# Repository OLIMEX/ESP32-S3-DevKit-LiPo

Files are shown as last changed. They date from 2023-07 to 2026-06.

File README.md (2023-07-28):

# ESP32-S3-DevKit-LiPo
ESP32-S3 development board with JTAG/USB-OTG and LiPo charger

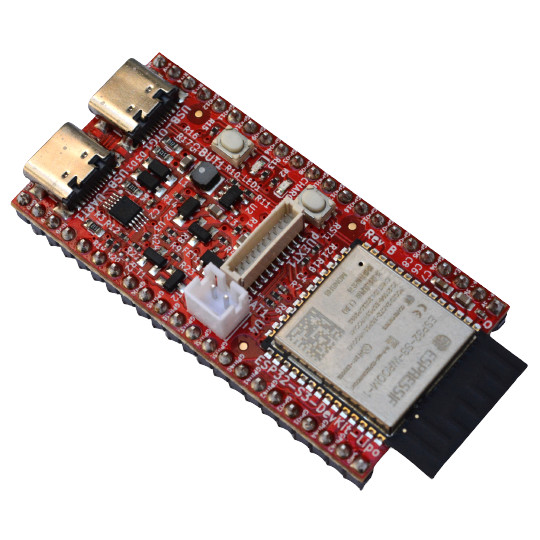
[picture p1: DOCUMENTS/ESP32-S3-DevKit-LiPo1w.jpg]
ESP32-S3-DevKit-LiPo1w


ESP32-S3-DevKit-LiPo is small board capable to run Linux kernel 6.3

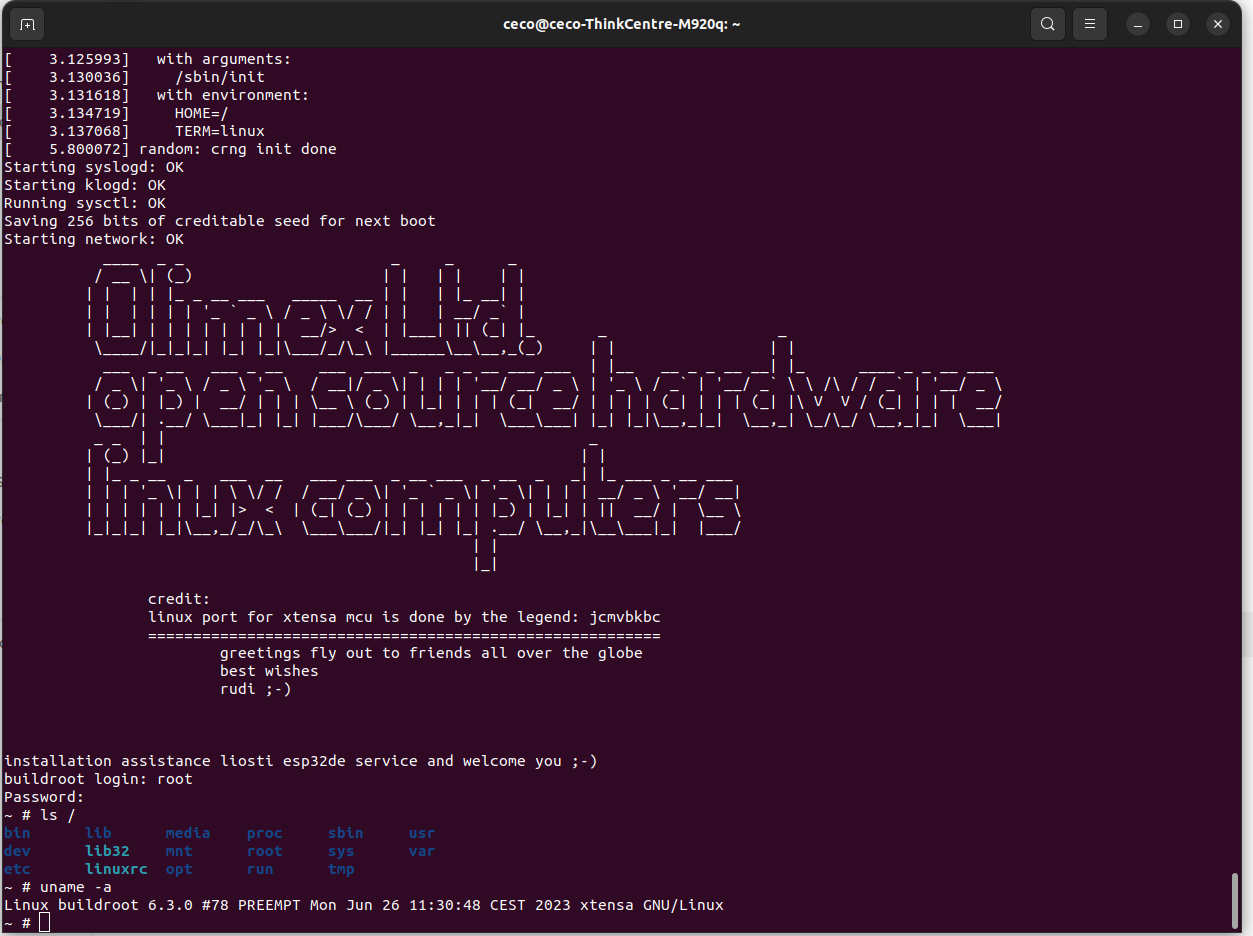
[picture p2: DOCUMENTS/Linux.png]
Linux


## Features

* ESP32-S3-WROOM-1-N8R8 8MB RAM 8 MB Flash
* Green Status LED
* Yellow Charge LED
* pUEXT connector
* USB-C power supply and USB-Serial programmer
* USB-C OTG JTAG/Serial connector
* LiPo charger
* LiPo battery connector
* External power sense
* Battery measurement
* Automatic power supply switch between USB and LiPo
* RESET button
* USER button

## Licenses

* Hardware is released under CERN Open Hardware Licence Version 2 - Strongly Reciprocal, all silkscreen credits to Olimex should remain;
* Software is released under GPL3 Licensee
* Documentation is released under CC BY-SA 3.0

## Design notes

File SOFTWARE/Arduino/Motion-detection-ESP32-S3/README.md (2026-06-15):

# CSI Motion and Position Demo

Arduino Wi-Fi CSI motion and room-zone sensing demo for the Olimex ESP32-S3-DevKit-LiPo and other ESP32-S3 boards.

This project lets you test two related ideas:

- Motion detection: show when something changes in the radio path.
- Position / room-zone detection: collect labels such as `empty`, `center`, `door`, or `desk`, then show a live browser-side guess.

Start with the one-board example. After that, use the multi-board receiver and transmitter examples for the real experiment.

## What You Need

- Arduino IDE 2.x, or Arduino IDE 1.8.x.
- ESP32 Arduino core installed in Arduino IDE.
- One Olimex ESP32-S3-DevKit-LiPo for the first test.
- For the recommended room test: three boards total.
  - 1 board runs `MultiBoardReceiverNode`.
  - 2 boards run `MultiBoardTransmitterNode`.
- USB cable for programming.
- Optional LiPo batteries for testing transmitters away from the computer.

No extra Arduino libraries are required. The examples use libraries that come with the ESP32 Arduino core: `WiFi`, `WebServer`, `WiFiUdp`, and `Preferences`.

## Install Arduino IDE

1. Download Arduino IDE from:
   - https://www.arduino.cc/en/software
2. Install it.
3. Start Arduino IDE once.

## Install ESP32 Board Support

Arduino IDE does not support ESP32 boards until you install the ESP32 board package.

1. Open Arduino IDE.
2. Go to `File > Preferences`.
3. Find `Additional boards manager URLs`.
4. Add this URL:

```text
https://espressif.github.io/arduino-esp32/package_esp32_index.json
```

5. Press `OK`.
6. Go to `Tools > Board > Boards Manager...`.
7. Search for `esp32`.
8. Install `esp32 by Espressif Systems`.
9. Restart Arduino IDE.

This is the stable ESP32 package URL from Espressif's Arduino-ESP32 install documentation:

- https://docs.espressif.com/projects/arduino-esp32/en/latest/installing.html

## Get This Project

When this project is on GitHub:

1. Open the GitHub repository page.
2. Press `Code`.
3. Press `Download ZIP`.
4. Extract the ZIP somewhere easy to find.

The project folder should contain files like this:

```text
CSI-Motion-and-Position-Demo/
  library.properties
  README.md
  src/
    MotionEsp32S3.h
    MotionEsp32S3.cpp
  examples/
    SingleBoardDashboard/
      SingleBoardDashboard.ino
    MultiBoardReceiverNode/
      MultiBoardReceiverNode.ino
    MultiBoardTransmitterNode/
      MultiBoardTransmitterNode.ino
    LoggerOnly/
      LoggerOnly.ino
```

The exact top folder name can be different. What matters is that `library.properties`, `src`, and `examples` are inside the same project folder.

## Install This Project In Arduino IDE

The easiest method is Arduino's ZIP library installer.

1. Make sure the whole project folder contains `library.properties`, `src`, and `examples`.
2. Zip the whole project folder.
3. In Arduino IDE, go to `Sketch > Include Library > Add .ZIP Library...`.
4. Select the ZIP file.
5. Wait for Arduino IDE to import it.
6. Check `File > Examples > CSI Motion and Position Demo`.

You should see:

- `SingleBoardDashboard`
- `MultiBoardReceiverNode`
- `MultiBoardTransmitterNode`
- `LoggerOnly`

If Arduino says the ZIP is invalid, the ZIP is probably nested incorrectly. Open the ZIP and check that it contains one project folder, and inside that folder are `library.properties`, `src`, and `examples`.

## Manual Install Option

Use this only if the ZIP installer does not work.

1. In Arduino IDE, open `File > Preferences`.
2. Note the `Sketchbook location`.
3. Open that folder in Windows Explorer.
4. Open or create the `libraries` folder.
5. Copy the whole project folder into `libraries`.

On Windows the final layout should look similar to:

```text
C:\Users\YOUR_NAME\Documents\Arduino\libraries\CSI_Motion_and_Position_Demo\
  library.properties
  src\
  examples\
```

Restart Arduino IDE after copying manually.

## Olimex ESP32-S3-DevKit-LiPo Board Settings

Connect the board through the onboard `USB-OTG1` native USB Type-C connector.

In Arduino IDE, select the board:

- `Tools > Board > esp32 > OLIMEX ESP32-S3-DevKit-Lipo`

If that exact board name is not available, update the ESP32 board package first. For quick experiments, a compatible ESP32-S3 board profile can work, but the Olimex profile is recommended for this board.

Settings tested with the USB-OTG1 connector:

| Arduino IDE menu | Value |
| --- | --- |
| Upload Speed | `921600` |
| USB Mode | `Hardware CDC and JTAG` |
| USB CDC On Boot | `Enabled` |
| USB Firmware MSC On Boot | `Disabled` |
| USB DFU On Boot | `Disabled` |
| Upload Mode | `USB-OTG CDC (TinyUSB)` |
| CPU Frequency | `240MHz (WiFi)` |
| Flash Mode | `QIO 80MHz` |
| Flash Size | `8MB (64Mb)` |
| Partition Scheme | `8M with spiffs (3MB APP/1.5MB SPIFFS)` |
| Core Debug Level | `None` |
| PSRAM | `OPI PSRAM` |
| Arduino Runs On | `Core 1` |
| Events Run On | `Core 1` |
| Erase All Flash Before Sketch Upload | `Disabled` |
| JTAG Adapter | `Disabled` |
| Port | the detected `ESP32 Family Device` COM port |

If you use an external USB-UART adapter instead of the native USB connector, the port and upload mode can be different.

## First Test: One Board

Use this first. It proves that the library, board package, upload, serial port, Wi-Fi, and dashboard all work.

1. Open Arduino IDE.
2. Go to `File > Examples > CSI Motion and Position Demo > SingleBoardDashboard`.
3. Edit these lines near the top:

```cpp
const char *WIFI_SSID = "YOUR_WIFI_NAME";
const char *WIFI_PASS = "YOUR_WIFI_PASSWORD";
```

4. Select your board and port in `Tools`.
5. Press `Upload`.
6. Open `Tools > Serial Monitor`.
7. Set baud rate to `115200`.

After Wi-Fi connects, Serial Monitor prints something like:

```text
Dashboard: http://192.168.0.139/
```

Open that address from a phone or computer on the same Wi-Fi network.

This one-board example joins your normal Wi-Fi network. It does not create its own access point.

Expected serial output looks like:

```text
score:0.55 threshold:1.10 motion:0 confidence:50 packets:656 links:1 best:F0:F5:BD:02:28:A0 rssi:-51
```

If you see changing packet counts and a dashboard in the browser, the basic setup works.

## One-Board Placement

For `SingleBoardDashboard`:

- Put the router/AP and the ESP32-S3 on opposite sides of the test area.
- Keep the board and router fixed.
- Keep the room still for the first 8 seconds after boot.
- Walk between the router and the board and watch the score.

This mode is only a quick proof. It depends on router traffic and the local Wi-Fi environment. The multi-board setup is more repeatable.

## Recommended Test: Three Boards

For a practical motion and position test, use three boards:

| Board | Example to flash | Role |
| --- | --- | --- |
| Board 1 | `MultiBoardReceiverNode` | Creates Wi-Fi AP and dashboard |
| Board 2 | `MultiBoardTransmitterNode` | Sends packets to receiver |
| Board 3 | `MultiBoardTransmitterNode` | Sends packets to receiver |

The receiver creates its own Wi-Fi network:

```text
SSID: MOTION-RX
Password: motion1234
Dashboard: http://192.168.4.1
```

Your room router is not needed for the multi-board demo.

## Flash The Receiver

1. Open `File > Examples > CSI Motion and Position Demo > MultiBoardReceiverNode`.
2. Select the Olimex ESP32-S3 board and port.
3. Upload.
4. Open Serial Monitor at `115200`.
5. Confirm it prints:

```text
Receiver access point started.
SSID: MOTION-RX
Password: motion1234
Dashboard: http://192.168.4.1/
```

## Flash The Transmitters

For the first transmitter:

1. Open `File > Examples > CSI Motion and Position Demo > MultiBoardTransmitterNode`.
2. Set:

```cpp
const char *NODE_ID = "node-1";
```

3. Upload to board 2.

For the second transmitter:

1. Keep the same sketch open.
2. Change:

```cpp
const char *NODE_ID = "node-2";
```

3. Upload to board 3.

The transmitters should keep these defaults unless you changed the receiver:

```cpp
const char *RX_SSID = "MOTION-RX";
const char *RX_PASS = "motion1234";
```

Serial Monitor on each transmitter prints its MAC address:

```text
Node MAC: B0:4E:26:6E:B2:73
```

Write down each transmitter MAC if you later want to use a custom allowlist.

## Open The Multi-Board Dashboard

1. Power the receiver.
2. Power the transmitter boards.
3. On your phone or laptop, connect to Wi-Fi network `MOTION-RX`.
4. Use password `motion1234`.
5. Open:

```text
http://192.168.4.1
```

The page title is `CSI Motion and Position Demo`.

The page has two tabs:

- `Motion`: live motion score and calibration.
- `Position`: label collection and live room-zone guess.

## Multi-Board Placement

Start simple:

- Put the receiver near one wall or corner.
- Put transmitter 1 on another side of the room.
- Put transmitter 2 on a different side of the room.
- The three boards should roughly form a triangle around the area.
- Keep antennas vertical.
- Keep all boards fixed during a test.
- Do not let boards swing from USB cables.

A person should cross at least one transmitter-to-receiver radio path when moving through the room.

For bigger rooms, 3 to 5 transmitters can be useful. The receiver tracks up to 8 active links, but the phone/laptop also uses one SoftAP client slot. If the dashboard `Dropped` counter rises quickly, reduce `PACKETS_PER_SECOND` in every transmitter to `25` to `35`.

## Motion Calibration

Use this after placing the receiver and transmitters:

1. Open `http://192.168.4.1`.
2. Go to the `Motion` tab.
3. Wait until active links appear.
4. Press `Reset baseline`.
5. Keep the room still.
6. Press `Learn idle`.
7. Stay still during the 8 second idle sample.
8. Press `Learn motion`.
9. Move through the path you want to detect during the 20 second motion sample.
10. Press `Apply suggested`.
11. Test normal movement and no movement.
12. Press `Save settings` if the threshold works well.

Lower threshold means more sensitive but more false positives. Higher threshold means fewer false positives but it can miss small motion.

## Position / Room-Zone Learning

Position mode is for labels such as:

- `empty`
- `center`
- `door`
- `desk`
- `bed`
- `sofa`

The model runs in the browser. It learns from the labels you collect during the current browser session.

Basic test with `empty` and `center`:

1. Open `http://192.168.4.1`.
2. Go to the `Position` tab.
3. Select label `empty`.
4. Leave the room empty and press `Start 60s`.
5. Wait until recording stops, or press `Stop`.
6. Select label `center`.
7. Stand in the center of the room and press `Start 60s`.
8. Wait until recording stops, or press `Stop`.
9. Watch `Live guess`.
10. Leave the room empty and check that it tends toward `empty`.
11. Stand in the center and check that it tends toward `center`.

The live guess is a simple nearest-centroid classifier. It compares the current CSI rows against the labels stored in the browser. It is meant for quick experiments, not precision indoor positioning.

Important:

- Keep all boards fixed while collecting all labels.
- If you move a board, collect the labels again.
- If you refresh or close the browser tab, the temporary model is lost.
- Press `Download CSV` before leaving the page if you want to keep the dataset.

## LoggerOnly Example

`LoggerOnly` is a smaller receiver sketch for data collection only.

Use it when:

- You want the simplest phone-friendly CSV logger.
- You do not need the full motion dashboard.
- You want optional CSV over USB Serial by setting:

```cpp
#define PRINT_SERIAL_CSV 1
```

For most users, start with `MultiBoardReceiverNode` instead.

## Filtering Links

The dashboard can show several links because it sees CSI from different Wi-Fi transmitters.

For `SingleBoardDashboard`, the default is to filter to the connected router/AP.

For `MultiBoardReceiverNode`, the default is:

```cpp
#define CSI_FILTER_MODE CSI_FILTER_NONE
```

This lets all transmitter nodes appear.

If phones or other clients appear as unwanted links, edit the receiver sketch:

```cpp
#define CSI_FILTER_MODE CSI_FILTER_CUSTOM_LIST
#define CSI_CUSTOM_MAC_COUNT 2
const uint8_t CSI_CUSTOM_MAC_ALLOWLIST[MotionEsp32S3::kMaxLinks][6] = {
  {0xB0, 0x4E, 0x26, 0x6E, 0xB2, 0x73},
  {0xF0, 0xF5, 0xBD, 0x02, 0x28, 0xA0},
};
```

Use the MAC addresses printed by each transmitter as `Node MAC: ...`.

## What The Dashboard Shows

- Motion score
- Motion/calm state
- Threshold
- Confidence
- Best link MAC
- Active links
- Per-link RSSI, score, packets, and state
- Dropped queue count
- Free heap and minimum free heap
- Motion calibration controls
- Position labels and live guess
- CSV download

Hover the mouse over dashboard buttons to see short tooltips.

## Troubleshooting

### The examples do not appear in Arduino IDE

- Restart Arduino IDE.
- Check that the ZIP was imported with `Sketch > Include Library > Add .ZIP Library...`.
- Check that `library.properties`, `src`, and `examples` are inside the installed library folder.

### ESP32 boards do not appear in the Board menu

- Recheck the Boards Manager URL.
- Install `esp32 by Espressif Systems` from Boards Manager.
- Restart Arduino IDE.

### Upload fails

- Check that the correct COM port is selected.
- Check the USB cable supports data, not only charging.
- For the Olimex USB-OTG1 connector, use the settings in this README.
- Try pressing the board reset button and uploading again.

### Serial Monitor shows nothing

- Set baud rate to `115200`.
- Press reset on the board.
- Make sure the sketch actually uploaded to this board.

### Single-board dashboard does not open

- Make sure the board joined your Wi-Fi.
- Your phone/computer must be on the same Wi-Fi network.
- Use the IP printed in Serial Monitor.

### Multi-board dashboard does not open

- Connect your phone/laptop to Wi-Fi `MOTION-RX`.
- Open `http://192.168.4.1`.
- Your normal room router is not used in this mode.

### No active links

- Make sure transmitter boards are powered.
- Make sure transmitters use `RX_SSID = "MOTION-RX"`.
- Keep the receiver powered before powering transmitters.

### Dropped count rises quickly

- Lower `PACKETS_PER_SECOND` in every `MultiBoardTransmitterNode`.
- Try `25` to `35` when using 4 or 5 transmitters.
- Keep the browser polling to one open dashboard tab.

### Position guess is wrong

- Collect longer samples, such as 120 seconds per label.
- Keep boards fixed.
- Make labels very different at first: `empty` and `center`.
- Add more transmitter paths if labels are not separable.
- Recollect all labels after moving any board.

## Library API For Custom Sketches

Minimal use:

```cpp
#include <MotionEsp32S3.h>

MotionEsp32S3 motion;

void setup() {
  // Start Wi-Fi first, then:
  MotionEsp32S3::Config config;
  config.threshold = 1.1f;
  motion.begin(config);
}

void loop() {
  if (motion.update()) {
    auto r = motion.reading();
    Serial.println(r.score);
  }
}
```

Start Wi-Fi before `motion.begin()`. The examples show both station mode and SoftAP mode.

For CSV logging:

- `fingerprintCsv()` returns the current highest-scoring active link.
- `fingerprintCsvAll()` returns one row per active link and is used by `MultiBoardReceiverNode` and `LoggerOnly`.

## Stability Notes

The ESP-IDF Wi-Fi CSI callbacks run from the Wi-Fi task. This library keeps the callback short by copying raw CSI bytes into a queue. Binning and detector math run later from `loop()`.

The dashboard examples pause CSI briefly while `Save settings` writes threshold/sensitivity to ESP32 flash. This avoids doing flash writes while CSI callbacks are active.

The dashboard shows heap as `currentK / minimumK`. If reboots continue, note the heap numbers before the reboot and save the full panic log.

## GitHub Publishing Checklist

Before publishing the repository, check that the root contains:

```text
README.md
library.properties
src/
examples/
```

Also consider adding:

- `LICENSE`
- screenshots of the dashboard
- photos or a diagram showing receiver/transmitter placement

Do not rename the `.ino` files without also renaming their containing folders. Arduino sketches require the folder name and `.ino` filename to match.

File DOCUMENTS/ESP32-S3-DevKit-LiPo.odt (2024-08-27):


ESP32-S3-DevKit-LiPo

User Manual

Document revision 2.0, August 2024 | www. (http://www.olimex.com/)o (http://www.olimex.com/)limex.com (http://www.olimex.com/)

# Introduction to ESP32-S3-DevKit-LiPo

ESP32-S3 is a dual-core XTensa LX7 MCU, capable of running at 240 MHz. Apart from its 512 KB of internal SRAM, it also comes with integrated 2.4 GHz, 802.11 b/g/n Wi-Fi and Bluetooth 5 (LE) connectivity that provides long-range support. It has 45 programmable GPIOs and supports a rich set of peripherals. ESP32-S3 supports larger, high-speed octal SPI flash, and PSRAM with configurable data and instruction cache.

The board has two variants: ESP32-S3-DevKit-Lipo comes with module with PCB antenna as seen in the picture on the first page, while ESP32-S3-DevKit-Lipo-EA comes with U.FL connector for external antenna.

ESP32-S3-DevKit-LiPo (https://www.olimex.com/Products/IoT/ESP32-S3/ESP32-S3-DevKit-Lipo/open-source-hardware) board is a development board with Espressif ESP32-S3 module and these features:

- ESP32-S3-WROOM-1-N8R8 8MB RAM 8MB flash
- Green status LED
- Yellow battery charge LED
- pUEXT 1.0 mm step connector
- USB-C for power supply and USB-serial programmer
- USB-C for OTG JTAG/serial connector
- LiPo battery charger
- LiPo battery connector
- External power sense
- Battery measurement
- Automatic power supply switch between USB and LiPo
- RESET button
- USER button
- Dimensions: (1.1×2.2)" ~ (27.94×55.88)mm

## Order codes for ESP32-S3-DevKit-Lipo and accessories:

ESP32-S3-DevKit-LiPo (https://www.olimex.com/Products/IoT/ESP32-S3/ESP32-S3-DevKit-Lipo/open-source-hardware) ESP32-S3 development board with USB JTAG/debugger and LiPo charger

USB-CABLE-A-TO-C-1M (https://www.olimex.com/Products/Components/Cables/CABLE-USB-A-C-1M/) USB-C power and programming cable

LiPo (https://www.olimex.com/Products/Power/Lipo-battery/) A number of compatible batteries

UEXT (https://www.olimex.com/Products/Modules/) Extension modules and sensors

# HARDWARE

## ESP32-S3-DevKit-LiPo layout:

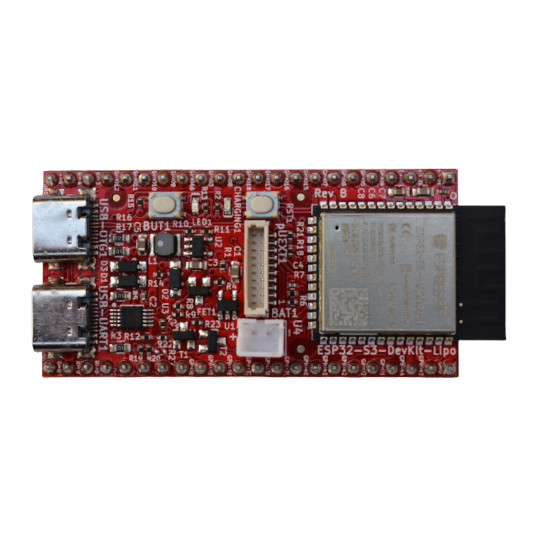
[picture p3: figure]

USB-C JTAG/OTG

USB-C UART

User Button

Status LED

ESP32-S3

pUEXT connector

LiPo battery connector

RESET

Charge LED

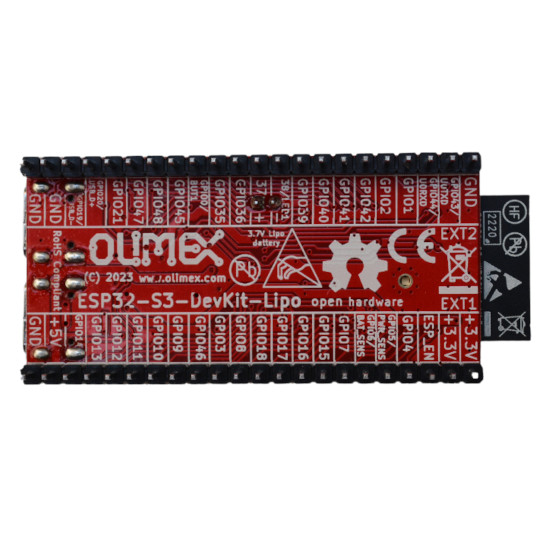
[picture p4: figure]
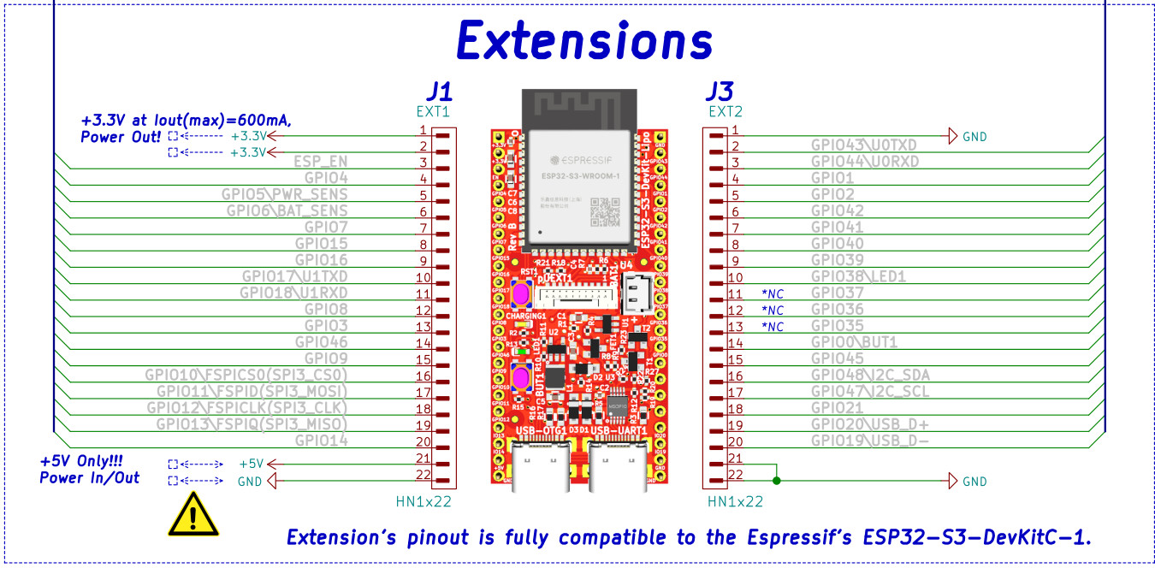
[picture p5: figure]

## ESP32-S3-DevKit-LiPo GPIOs:

POWER SUPPLY:

This board can be powered by:

+5V EXT1.pin 21 can be input or output

USB-UART USB-C connector

USB-OTG1 USB-C connector

LiPo battery

## ESP32-S3-DevKit-Lipo schematics:

ESP32-S3-DevKit-LiPo (https://www.olimex.com/Products/IoT/ESP32-S3/ESP32-S3-DevKit-Lipo/open-source-hardware) latest schematic is on GitHub (https://github.com/OLIMEX/RP2040-PICO30)

## UEXT connector:

UEXT connector stands for Universal EXTension connector and contain +3.3V, GND, I2C, SPI, UART signals.

UEXT connector can be in different shapes.

The original UEXT connector is 0.1” 2.54mm step boxed plastic connector. All signals are with 3.3V levels.

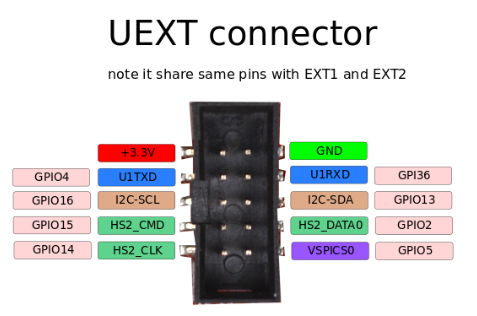
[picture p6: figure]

As the boards become smaller and smaller some smaller packages were introduced too beside the original UEXT connector

- mUEXT is 1.27 mm step boxed header connector which is with same layout as UEXT

- pUEXT is 1.0 mm single row connector (this is the connector used in RP2040-PICO30)

Olimex has developed number of MODULES (https://www.olimex.com/Products/Modules/) with this connector. There are temperature, humidity, pressure, magnetic field, light sensors. Modules with LCDs, LED matrix, Relays, Bluetooth, Zigbee, WiFi, GSM, GPS, RFID, RTC, EKG, sensors and etc.

## pUEXT signals:

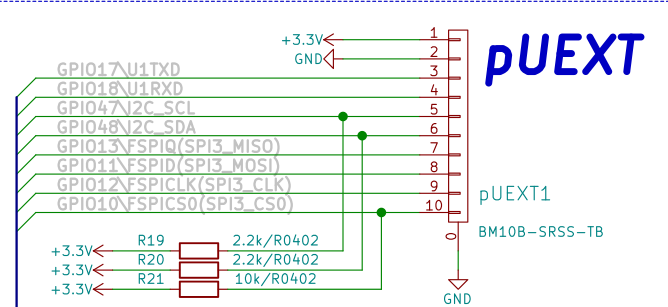
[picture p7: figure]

# SOFTWARE:

Olimex ESP32-S3-DevKit-LiPo has support in the ESP32 package for Arduino IDE. From the board selector there is entry “OLIMEX ESP32-S3-DevKit-Lipo”.

The module is also supported in ESP-IDF.

Additionally we’ve seen some customer project for booting Linux off the board:

- ESP32-S3-DevKit-Lipo Linux image (https://github.com/ESP32DE/Boot-Linux-ESP32S3-Playground/blob/main/bins/S3/olimexS3WROOM_N8qdR8ot.bin)
- ESP32-S3-DevKit-LiPo Linux build instructions (https://github.com/jcmvbkbc/linux-xtensa)from jcmvbkbc and here (https://gist.github.com/jcmvbkbc/316e6da728021c8ff670a24e674a35e6)
- ESP32-S3-DevKit-Lipo Linux build instructions (https://github.com/ESP32DE/Boot-Linux-ESP32S3-Playground) form ESP32DE

# Revision History

Revision 1.0 July 2023

Revision 2.0 August 2024

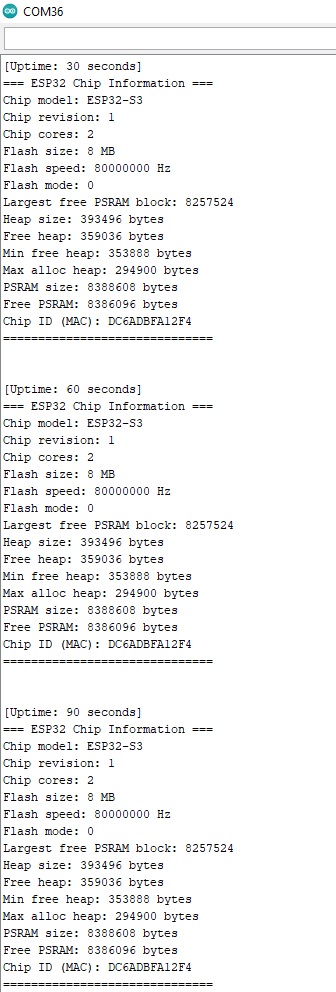
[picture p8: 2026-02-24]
SOFTWARE/Arduino/ESP32-S3-chip-info-demo/Expected-serial-output.jpg

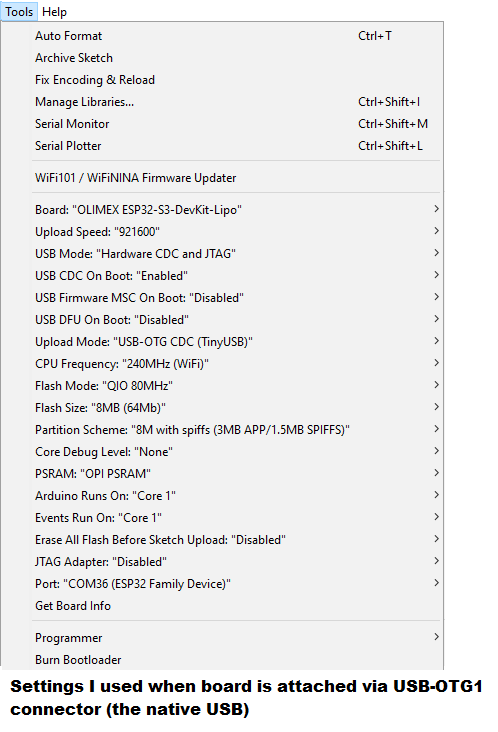
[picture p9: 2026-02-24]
SOFTWARE/Arduino/ESP32-S3-chip-info-demo/Arduino-Settings.jpg

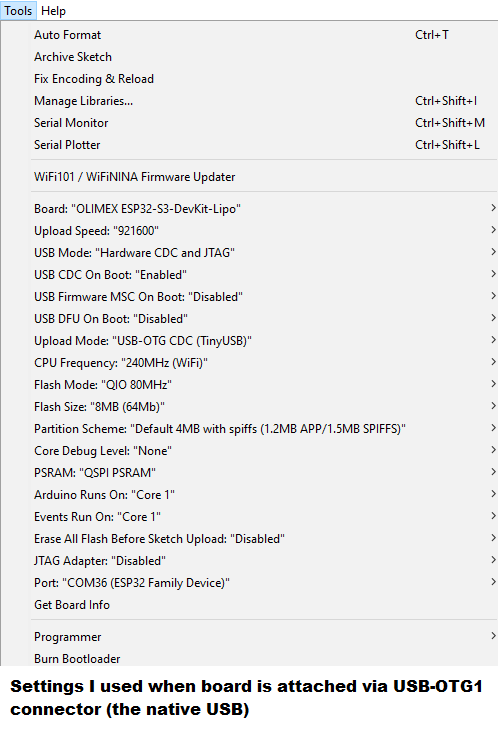
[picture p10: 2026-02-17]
SOFTWARE/Arduino/ESP32-S3-DevKit-Lipo-bat-sense/Arduino-Settings.jpg

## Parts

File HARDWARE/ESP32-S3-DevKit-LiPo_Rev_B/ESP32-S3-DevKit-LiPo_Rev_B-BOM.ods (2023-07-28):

Qty | Designation | Package | Designator
2 | 100R/R0402 | R_0402_5MIL_DWS | R15,R24
2 | 1k/R0402 | R_0402_5MIL_DWS | R22,R23
4 | 2.2k/R0402 | R_0402_5MIL_DWS | R13,R2,R19,R20
1 | 4.7k/R0402 | R_0402_5MIL_DWS | R12
4 | 5.1k/R0603 | R_0603_5MIL_DWS | R5,R3,R16,R17
5 | 10k/R0402 | R_0402_5MIL_DWS | R18,R1,R4,R14,R21
1 | 49.9k/1%/R0402 | R_0402_5MIL_DWS | R11
1 | 150k/R0402 | R_0402_5MIL_DWS | R7
2 | 220k/R0402 | R_0402_5MIL_DWS | R10,R8
2 | 470k/R0402 | R_0402_5MIL_DWS | R6,R9
3 | 100nF/10V/10%/X7R/C0402 | C_0402_5MIL_DWS | C2,C7,C4
1 | 1uF/10V/10%/X5R/C0603 | C_0603_5MIL_DWS | C8
4 | 22uF/6.3V/20%/X5R/C0603 | C_0603_5MIL_DWS | C5,C6,C1,C3
3 | 1N5819S4/SOD123 | SOD-123_1C-2A_KA | D1,D3,D2
1 | LED/Green/0603 | LED_0603_KA | LED1
1 | LED/YELLOW/0603 | LED_0603_KA | CHARGING1
1 | 2.2uH/1.5A/DCR=72mR/20%/3x3x 1.5mm/CD32(NR3015T2R2M) | CD32 | L1
1 | WPM2015-3/TR | SOT23 | FET1
2 | BC817-40(SOT23) | SOT23 | T1,T2
1 | BL4054B-42TPRN(SOT23-5) | SOT-23-5 | U1
1 | SY8089AAAC(SOT23-5) | SOT-23-5 | U2
1 | CH340X(MSOP-10) | MSOP-10_Pitch-0.5mm_3.00x3.00x1.00mm | U3
1 | ESP32-S3-WROOM-1-N8R8 | ESP32-Â-S3-Â-WROOMÂ-1 | U4
1 | DW02S | LIPO_BAT_VERTICAL_DW02S | BAT1
1 | BM10B-SRSS-TB | BM10B-SRSS-TB | pUEXT1
2 | HN1x22 | HN1x22 | EXT2,EXT1
2 | USB-C-16P-F(A40-00119-A52-12) | USB2.0_TYPE-C(A40-00119-A52-12) | USB-OTG1,USB-UART1
2 | YTS-A016-X | YTS-A016-X | BUT1,RST1
1 | NA/R0402 | R_0402_5MIL_DWS | R27

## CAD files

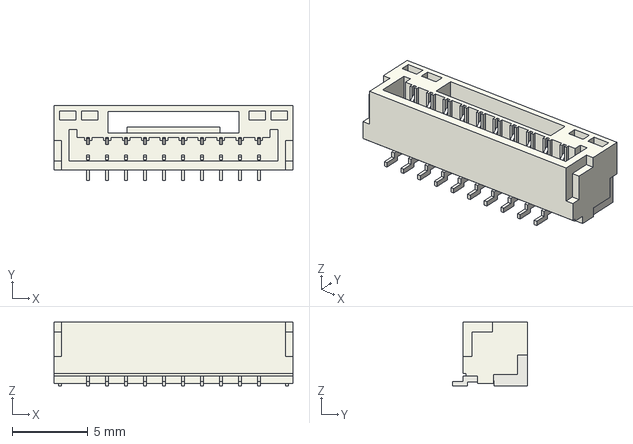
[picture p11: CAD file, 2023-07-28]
HARDWARE/ESP32-S3-DevKit-LiPo_Rev_B/3d/BM10B-SRSS-TB(JST_GH_BM10B-GHS-TBT_1x10-1MP_P1.25mm_Vertical).step
15.8 x 4.95 x 4.20 mm

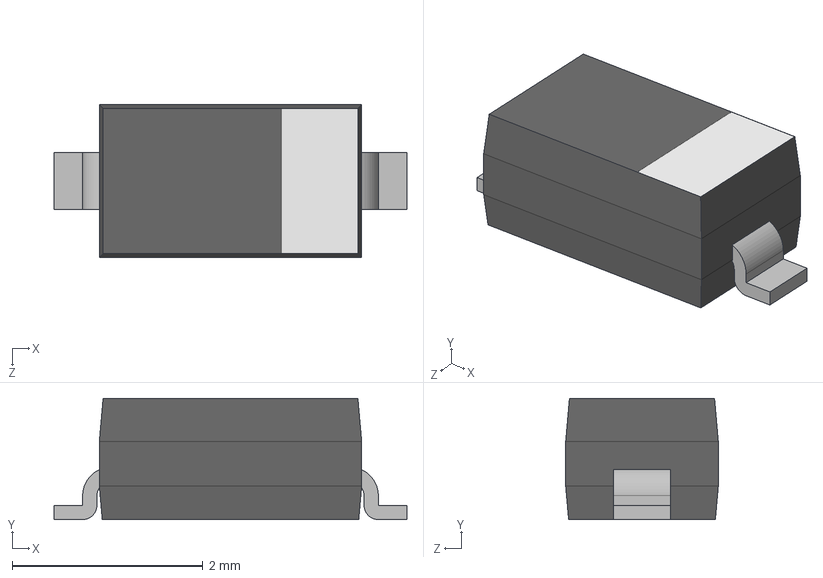
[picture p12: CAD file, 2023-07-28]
HARDWARE/ESP32-S3-DevKit-LiPo_Rev_B/3d/SOD123.step
3.70 x 1.27 x 1.60 mm

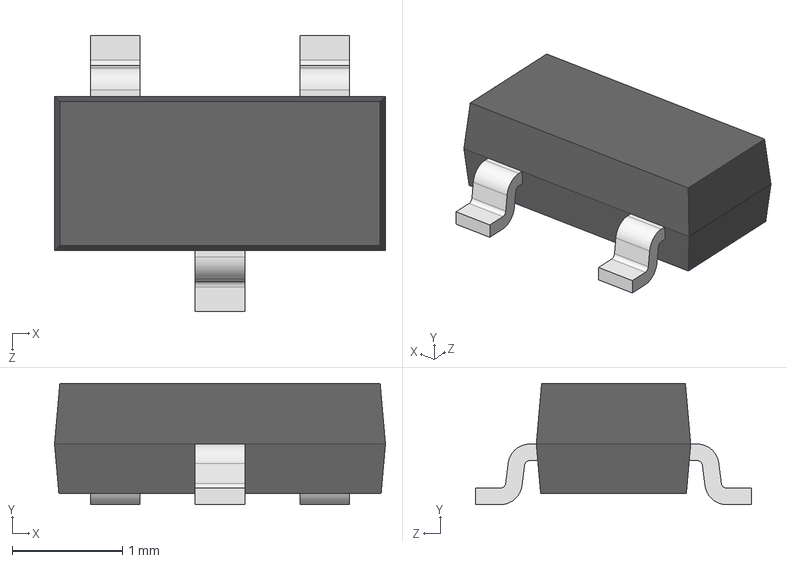
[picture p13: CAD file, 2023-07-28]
HARDWARE/ESP32-S3-DevKit-LiPo_Rev_B/3d/SOT-23.step
3.00 x 1.10 x 2.50 mm

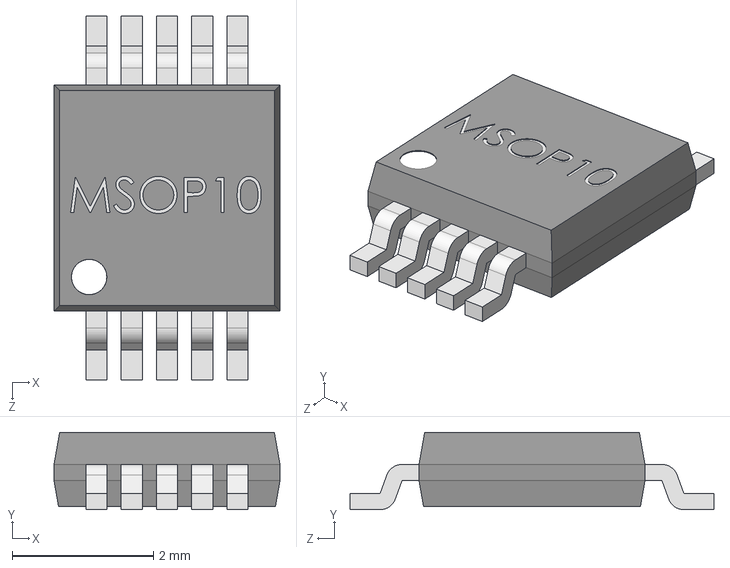
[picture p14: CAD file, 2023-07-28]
HARDWARE/ESP32-S3-DevKit-LiPo_Rev_B/3d/MSOP10-1.step
3.20 x 1.10 x 5.15 mm

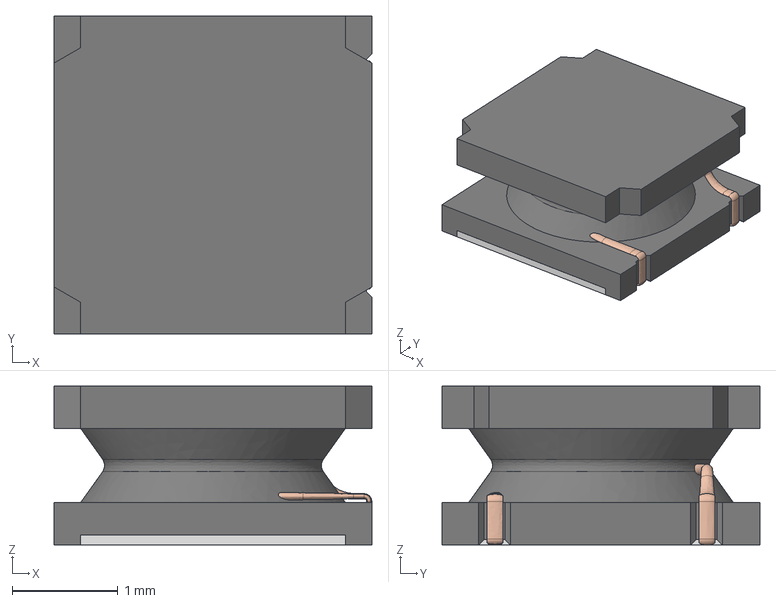
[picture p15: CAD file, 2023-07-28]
HARDWARE/ESP32-S3-DevKit-LiPo_Rev_B/3d/L-CD32_shielded.step
3.00 x 3.00 x 1.50 mm

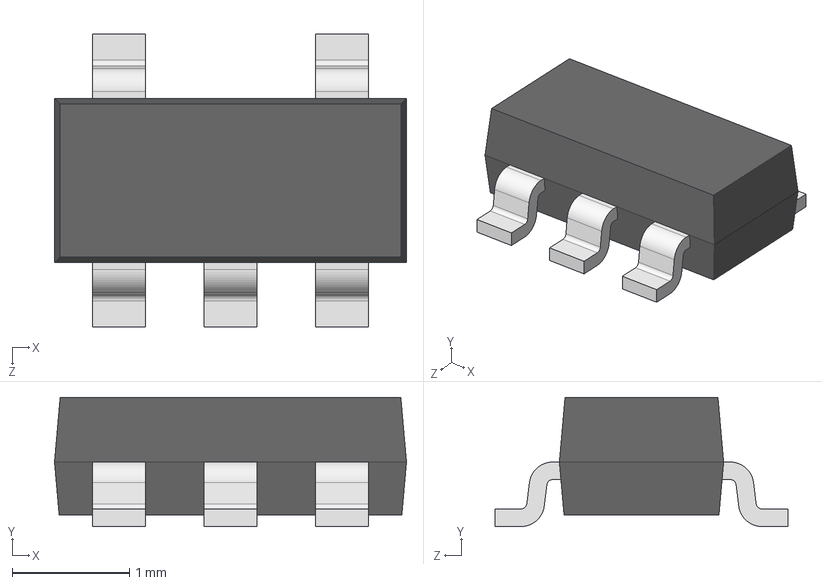
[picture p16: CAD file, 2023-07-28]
HARDWARE/ESP32-S3-DevKit-LiPo_Rev_B/3d/SOT-23-5.step
3.00 x 1.10 x 2.50 mm

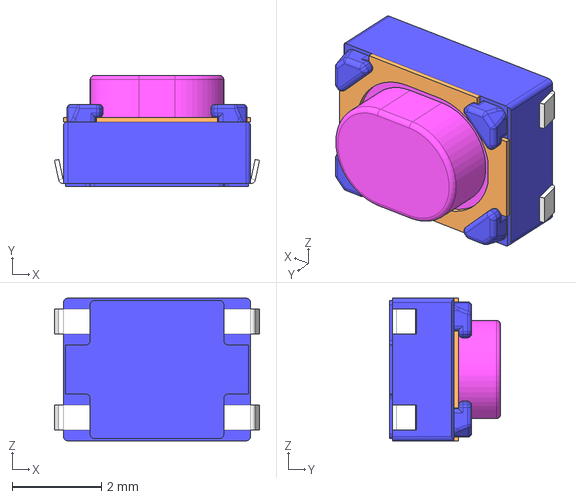
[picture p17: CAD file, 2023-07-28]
HARDWARE/ESP32-S3-DevKit-LiPo_Rev_B/3d/YTS-A016-X(SKRPABE010).stp
4.60 x 2.50 x 3.20 mm

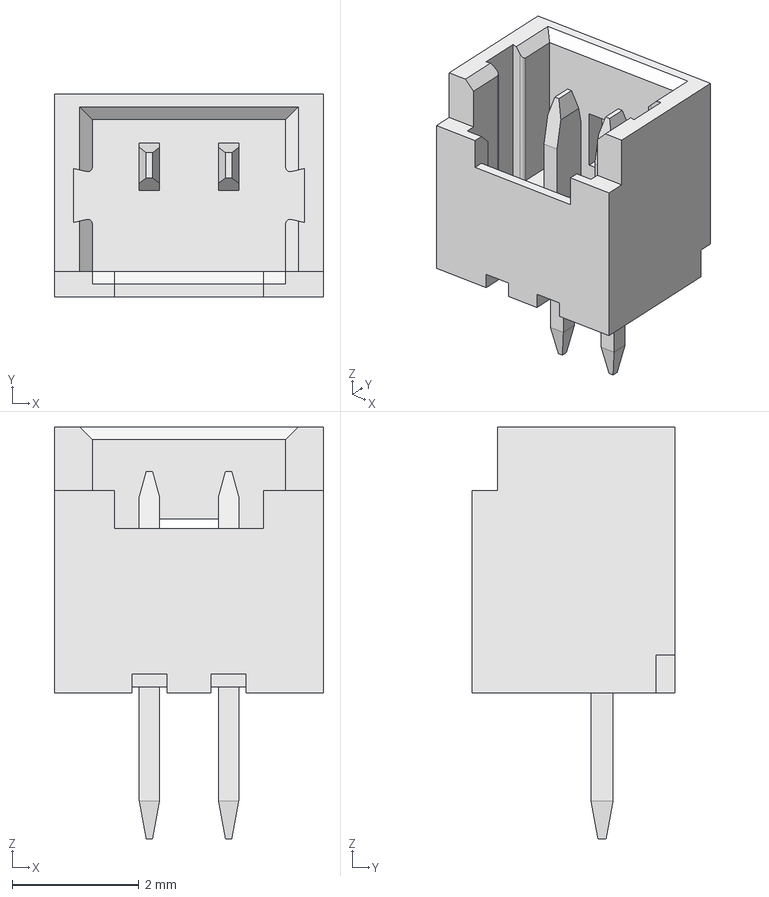
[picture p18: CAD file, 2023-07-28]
HARDWARE/ESP32-S3-DevKit-LiPo_Rev_B/3d/Molex_PicoBlade_530470210.step
4.25 x 3.20 x 6.50 mm

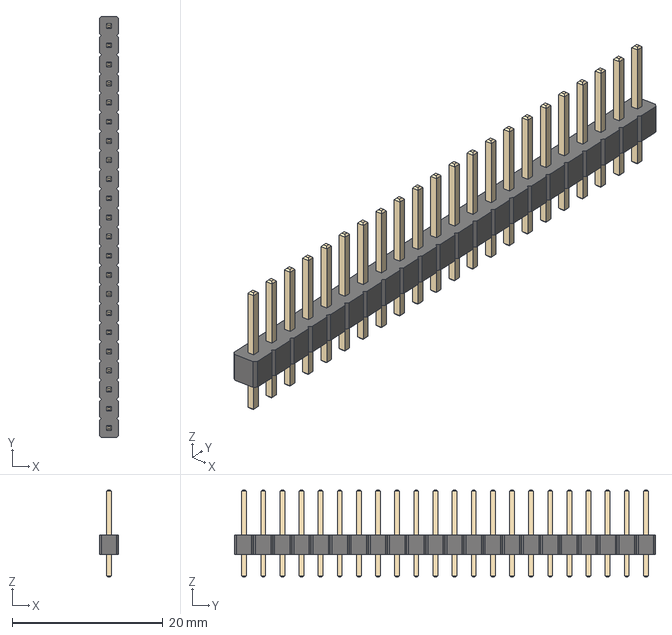
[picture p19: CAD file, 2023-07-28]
HARDWARE/ESP32-S3-DevKit-LiPo_Rev_B/3d/HN1x22-PinHeader_1x22_P2.54mm_Vertical.step
2.54 x 55.9 x 11.5 mm

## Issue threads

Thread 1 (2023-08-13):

Can't login as root and blank password on putty

manobendro, 2023-08-13:
I flash olimexS3WROOM_N8qdR8ot.bin rom on yd-esp32-s3-n16-r8 and putty for serial communication with the esp32 board. But I can't log into Linux with username root and password keeping empty. Can anyone tell me the root password or do I need to change the configuration on putty?

ESP32DE, 2024-08-25:
read commit message to the bin helps
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
@manobendro

Closed 2024-08-27.

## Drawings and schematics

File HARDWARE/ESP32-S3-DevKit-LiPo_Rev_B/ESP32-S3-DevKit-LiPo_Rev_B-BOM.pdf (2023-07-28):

ESP32-S3-DevKit-LiPo_Rev_B | 05/17/2023

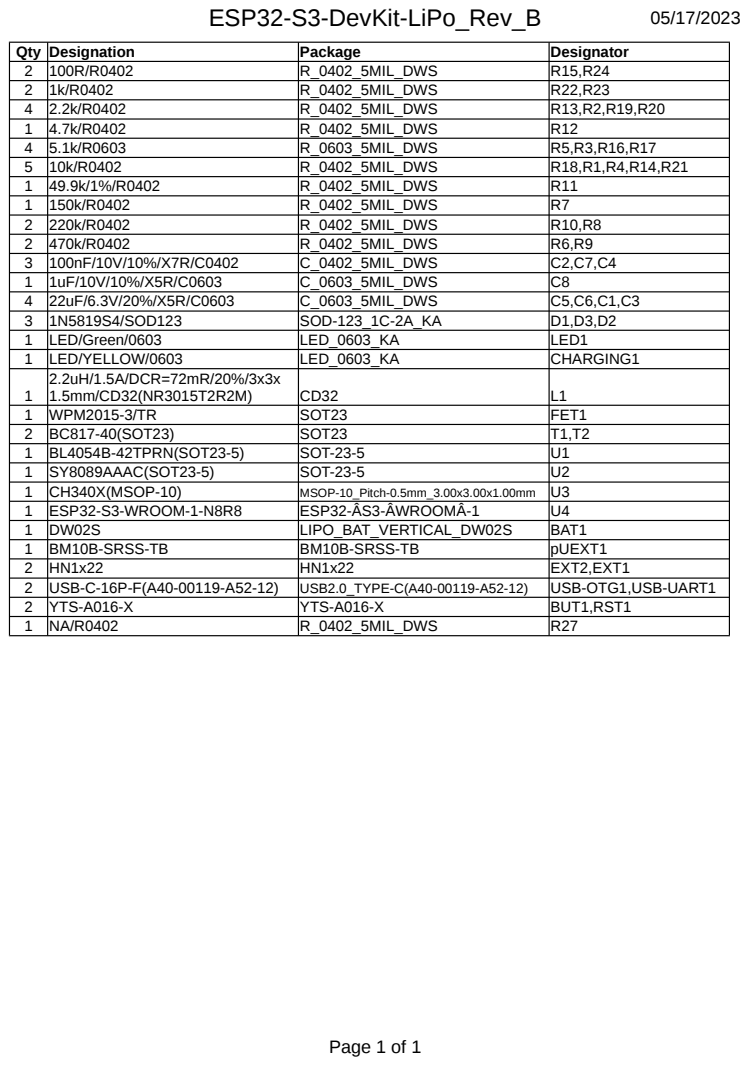
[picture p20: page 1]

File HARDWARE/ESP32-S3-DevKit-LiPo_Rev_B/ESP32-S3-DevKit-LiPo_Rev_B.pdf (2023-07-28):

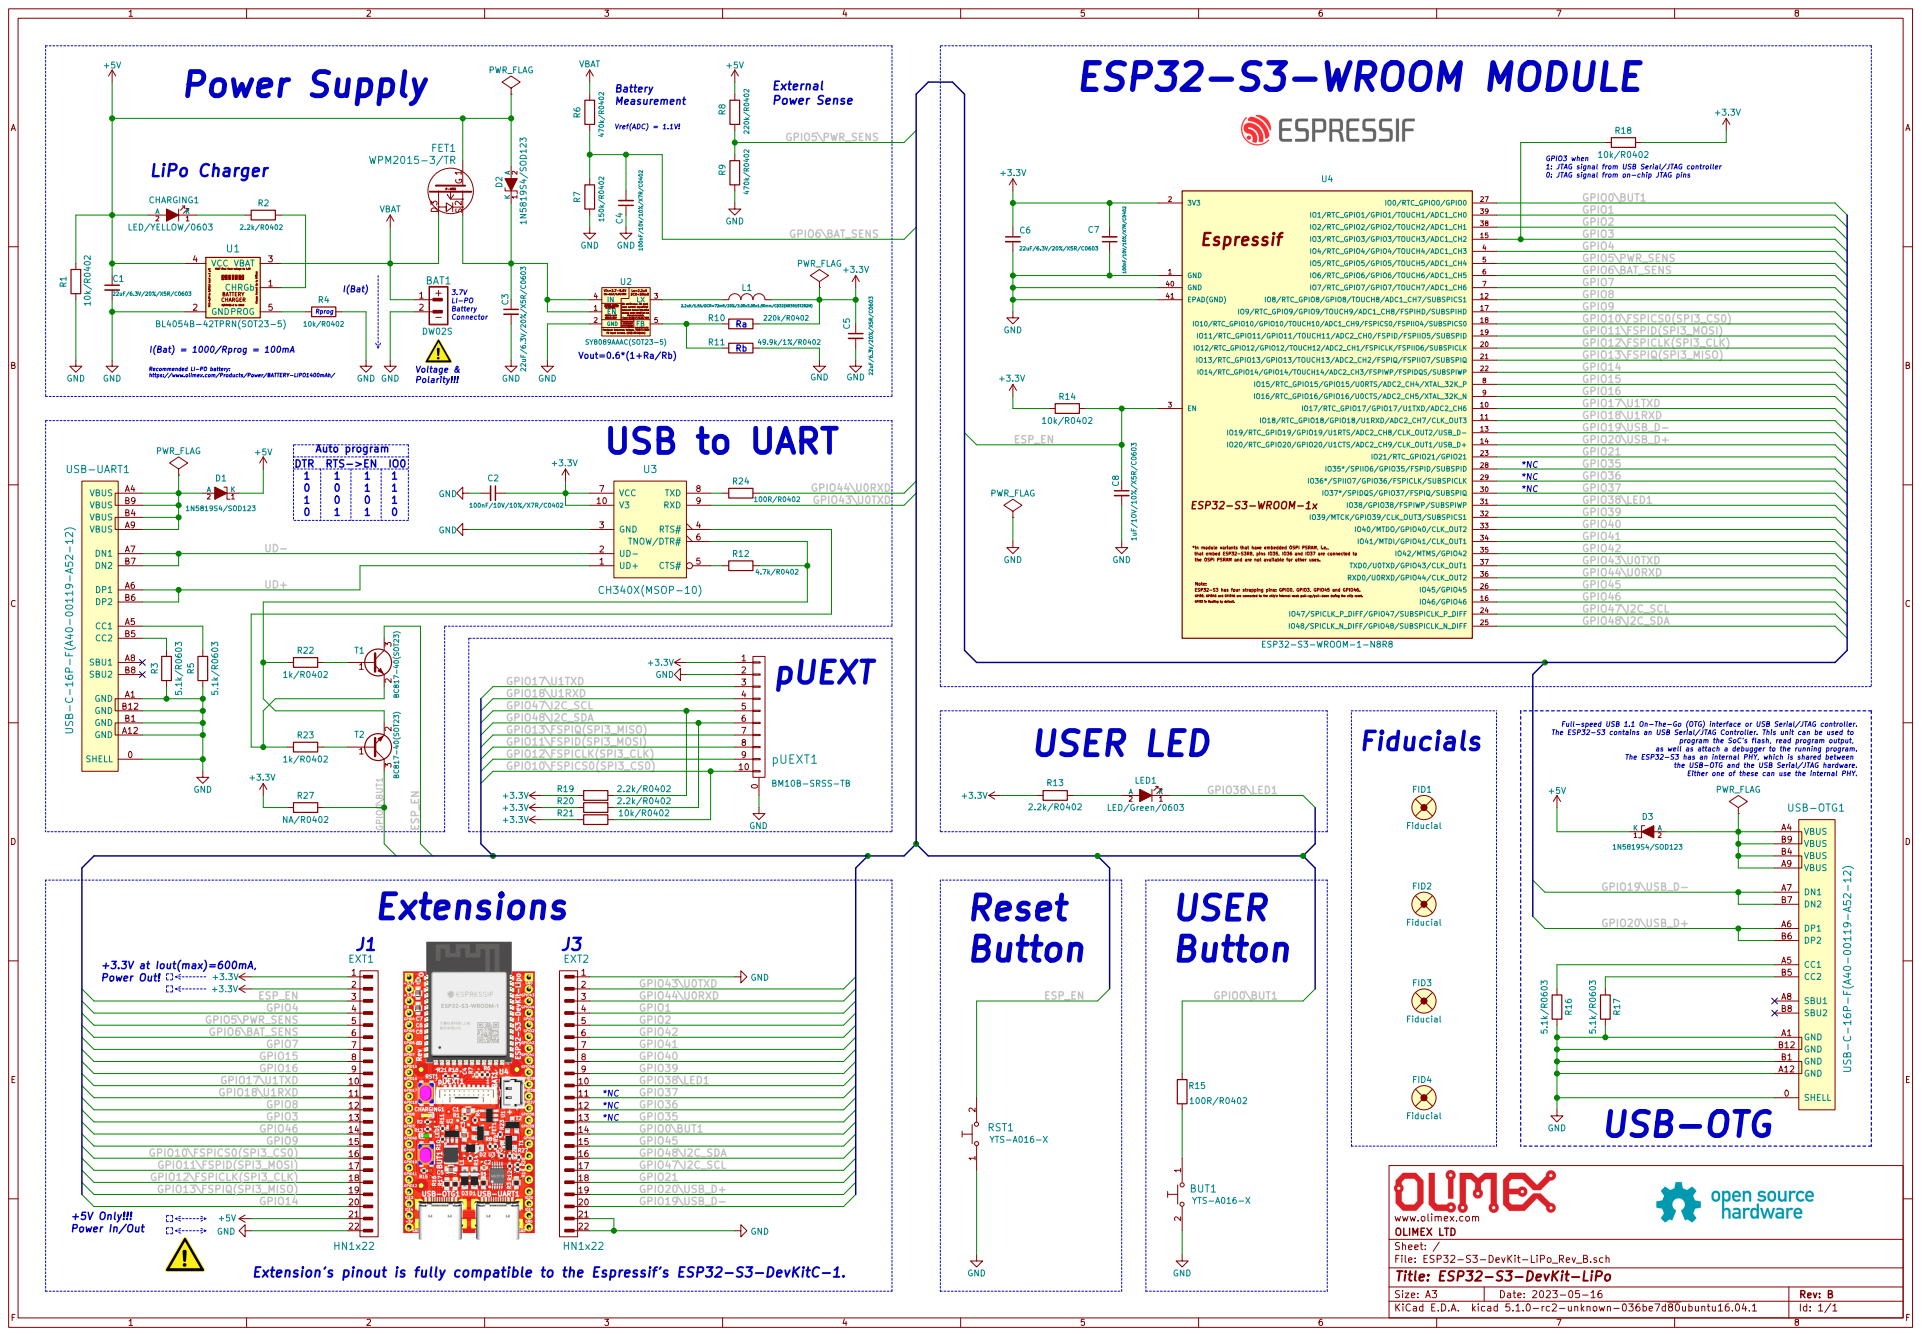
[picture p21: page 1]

External
Power Sense
the OSPI PSRAM and are not available for other uses. GND 1

10k/R0402 GPIO3 when 1: JTAG signal from USB Serial/JTAG controller 0: JTAG signal from on-chip JTAG pins

Full-speed USB 1.1 On-The-Go (OTG) interface or USB Serial/JTAG controller. The ESP32-S3 contains an USB Serial/JTAG Controller. This unit can be used to program the SoCs flash, read program output, as well as attach a debugger to the running program. The ESP32-S3 has an internal PHY, which is shared between the USB-OTG and the USB Serial/JTAG hardware. Either one of these can use the internal PHY. GPIO6\BAT_SENS

load current capability! Lx=2.2uH

Do not float. Enable control. FB Input Current, I(FB)=50nA(max) Feedback Reference Voltage, V(REF)=0.6V

*In module variants that have embedded OSPI PSRAM, i.e., ESP32-S3 has four strapping pins: GPIO0, GPIO3, GPIO45 and GPIO46. ESP32-S3-WROOM-1x

that embed ESP32-S3R8, pins IO35, IO36 and IO37 are connected to

GPIO0, GPIO45 and GPIO46 are connected to the chips internal weak pull-up/pull-down during the chip reset. GPIO3 is floating by default. Note:

9EXT1 HN1x22 Extension's pinout is fully compatible to the Espressif's ESP32-S3-DevKitC-1.
+3.3V GND
ESP_EN GPIO4 GPIO5\PWR_SENS

www.olimex.com
File: ESP32-S3-DevKit-LiPo_Rev_B.sch Sheet: / OLIMEX LTD

Id: 1/1 Title: ESP32-S3-DevKit-LiPo

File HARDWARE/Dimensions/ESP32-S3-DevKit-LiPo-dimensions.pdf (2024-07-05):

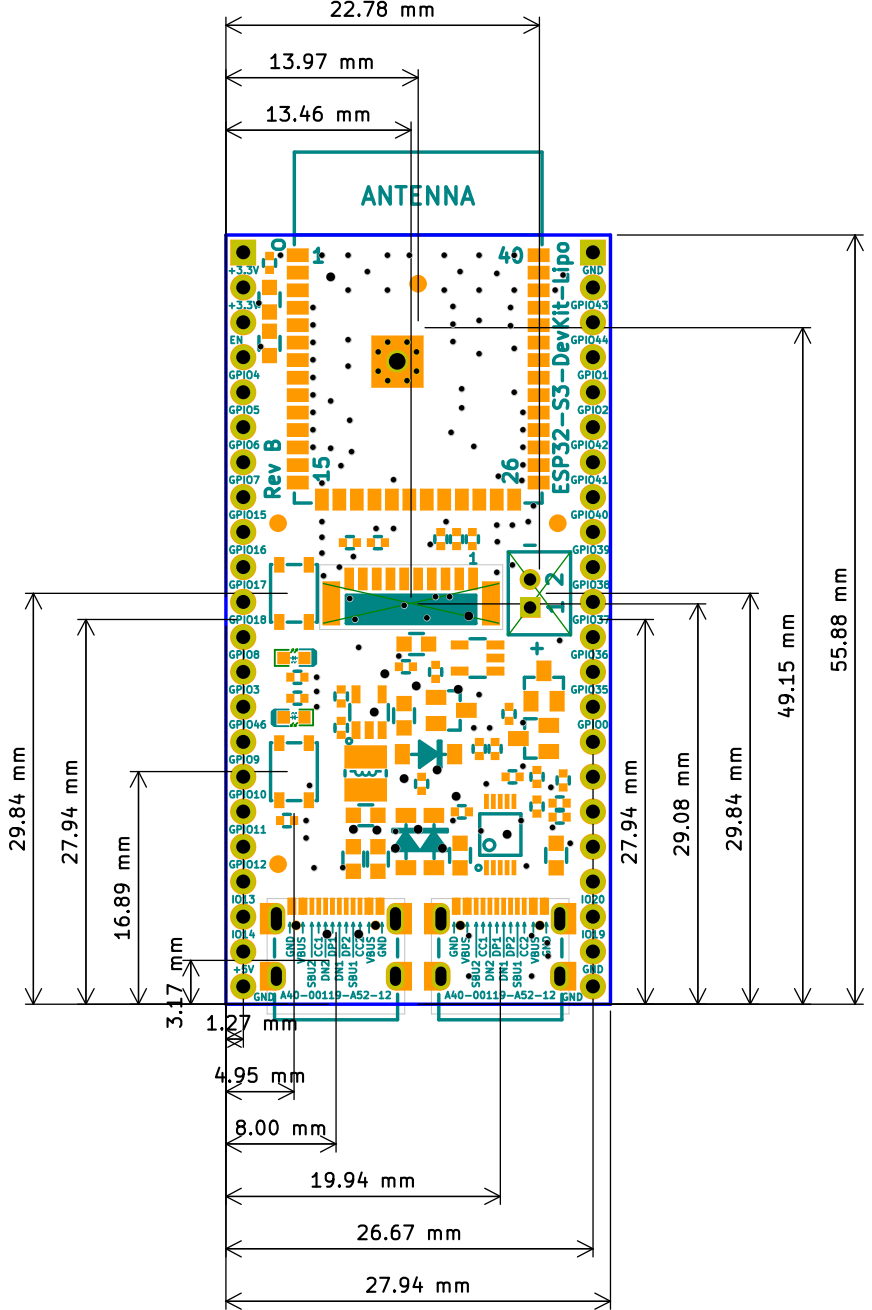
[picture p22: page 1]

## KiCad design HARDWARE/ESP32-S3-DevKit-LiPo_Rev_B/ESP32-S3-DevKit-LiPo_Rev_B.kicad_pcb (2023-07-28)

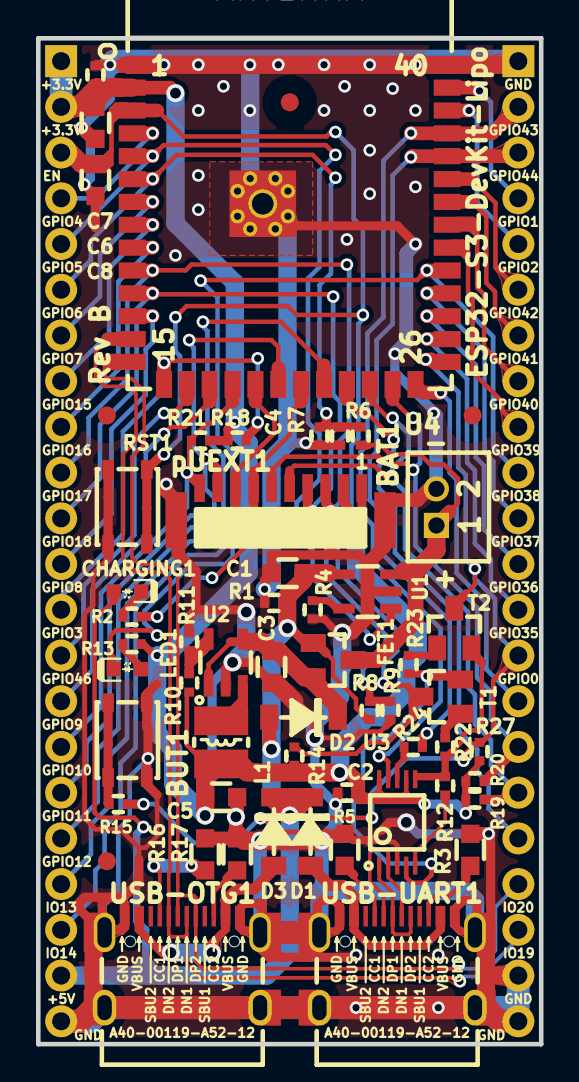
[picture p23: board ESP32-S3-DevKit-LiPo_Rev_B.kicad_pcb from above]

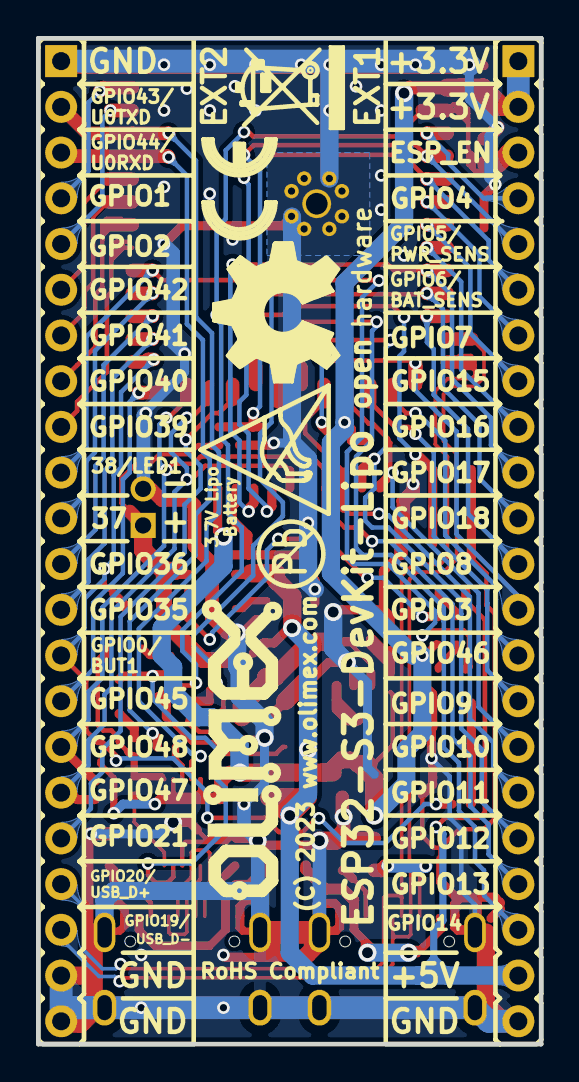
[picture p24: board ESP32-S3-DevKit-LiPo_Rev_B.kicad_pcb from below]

Board: 2 copper layers, 27.9 x 55.9 mm, 64 parts (8 on the bottom side), 63 nets.

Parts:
BAT1: DW02S; LIPO_BAT_VERTICAL_DW02S
BUT1: YTS-A016-X
C1, C3, C5, C6: 22uF/6.3V/20%/X5R/C0603; C_0603_5MIL_DWS
C2, C4, C7: 100nF/10V/10%/X7R/C0402; C_0402_5MIL_DWS
C8: 1uF/10V/10%/X5R/C0603; C_0603_5MIL_DWS
CHARGING1: LED/YELLOW/0603; LED_0603_KA
D1, D2, D3: 1N5819S4/SOD123; SOD-123_1C-2A_KA
EXT1, EXT2: HN1x22
FET1: WPM2015-3/TR; SOT23
FID1, FID2, FID3, FID4: Fiducial; Fiducial1x3
L1: 2.2uH/1.5A/DCR=72mR/20%/3.00x3.00x1.50mm/CD32(NR3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; CD32
LED1: LED/Green/0603; LED_0603_KA
Logo_OLIMEX_TB: Logo_OLIMEX_TB
R1, R4, R14, R18, R21: 10k/R0402; R_0402_5MIL_DWS
R2, R13, R19, R20: 2.2k/R0402; R_0402_5MIL_DWS
R3, R5, R16, R17: 5.1k/R0603; R_0603_5MIL_DWS
R6, R9: 470k/R0402; R_0402_5MIL_DWS
R7: 150k/R0402; R_0402_5MIL_DWS
R8, R10: 220k/R0402; R_0402_5MIL_DWS
R11: 49.9k/1%/R0402; R_0402_5MIL_DWS
R12: 4.7k/R0402; R_0402_5MIL_DWS
R15, R24: 100R/R0402; R_0402_5MIL_DWS
R22, R23: 1k/R0402; R_0402_5MIL_DWS
R27: NA/R0402; R_0402_5MIL_DWS
RST1: YTS-A016-X
Sign_Antistatic: Sign_Antistatic
Sign_CE: CE_Sign
Sign_OSHW_8x8: Sign_OSHW_8x8
Sign_PB-Free: Sign_PB-Free
Sign_RecycleBin_1: Sign_RecycleBin_1
T1, T2: BC817-40(SOT23); SOT23
U1: BL4054B-42TPRN(SOT23-5); SOT-23-5
U2: SY8089AAAC(SOT23-5); SOT-23-5
U3: CH340X(MSOP-10); MSOP-10_Pitch-0.5mm_3.00x3.00x1.00mm
U4: ESP32-S3-WROOM-1-N8R8; ESP32-­S3-­WROOM­-1
USB-OTG1: USB-C-16P-F(A40-00119-A52-12); USB2.0_TYPE-C(A40-00119-A52-12)
USB-UART1: USB-C-16P-F(A40-00119-A52-12); USB2.0_TYPE-C(A40-00119-A52-12)
pUEXT1: JST_BM10B-SRSS-TB; BM10B-SRSS-TB

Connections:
+3.3V: C2.1, C5.1, C6.1, C7.2, EXT1.1, EXT1.2, L1.2, R10.2, R13.1, R14.1, R18.1, R19.1, R20.1, R21.1, R27.1, U3.7, U3.10, U4.2, pUEXT1.1
+5V: C1.1, CHARGING1.2, D1.1, D2.2, D3.1, EXT1.21, FET1.1, R1.1, R8.1, U1.4
/ESP_EN: C8.1, EXT1.3, R14.2, RST1.2, T1.3, U4.3
/GPIO0\BUT1: EXT2.14, R15.1, R27.2, T2.3, U4.27
/GPIO1: EXT2.4, U4.39
/GPIO2: EXT2.5, U4.38
/GPIO3: EXT1.13, R18.2, U4.15
/GPIO4: EXT1.4, U4.4
/GPIO5\PWR_SENS: EXT1.5, R8.2, R9.1, U4.5
/GPIO6\BAT_SENS: C4.2, EXT1.6, R6.2, R7.1, U4.6
/GPIO7: EXT1.7, U4.7
/GPIO8: EXT1.12, U4.12
/GPIO9: EXT1.15, U4.17
/GPIO10\FSPICS0(SPI3_CS0): EXT1.16, R21.2, U4.18, pUEXT1.10
/GPIO11\FSPID(SPI3_MOSI): EXT1.17, U4.19, pUEXT1.8
/GPIO12\FSPICLK(SPI3_CLK): EXT1.18, U4.20, pUEXT1.9
/GPIO13\FSPIQ(SPI3_MISO): EXT1.19, U4.21, pUEXT1.7
/GPIO14: EXT1.20, U4.22
/GPIO15: EXT1.8, U4.8
/GPIO16: EXT1.9, U4.9
/GPIO17\U1TXD: EXT1.10, U4.10, pUEXT1.3
/GPIO18\U1RXD: EXT1.11, U4.11, pUEXT1.4
/GPIO19\USB_D-: EXT2.20, U4.13, USB-OTG1.A7, USB-OTG1.B7
/GPIO20\USB_D+: EXT2.19, U4.14, USB-OTG1.A6, USB-OTG1.B6
/GPIO21: EXT2.18, U4.23
/GPIO35: EXT2.13, U4.28
/GPIO36: EXT2.12, U4.29
/GPIO37: EXT2.11, U4.30
/GPIO38\LED1: EXT2.10, LED1.1, U4.31
/GPIO39: EXT2.9, U4.32
/GPIO40: EXT2.8, U4.33
/GPIO41: EXT2.7, U4.34
/GPIO42: EXT2.6, U4.35
/GPIO43\U0TXD: EXT2.2, U3.9, U4.37
/GPIO44\U0RXD: EXT2.3, R24.2, U4.36
/GPIO45: EXT2.15, U4.26
/GPIO46: EXT1.14, U4.16
/GPIO47\I2C_SCL: EXT2.17, R19.2, U4.24, pUEXT1.5
/GPIO48\I2C_SDA: EXT2.16, R20.2, U4.25, pUEXT1.6
/UD+: U3.1, USB-UART1.A6, USB-UART1.B6
/UD-: U3.2, USB-UART1.A7, USB-UART1.B7
GND: BAT1.2, BUT1.2, C1.2, C2.2, C3.2, C4.1, C5.2, C6.2, C7.1, C8.2, EXT1.22, EXT2.1, EXT2.21, EXT2.22, R1.2, R3.1, R4.2, R5.1, R7.2, R9.2, R11.2, R16.1, R17.1, RST1.1, U1.2, U2.2, U3.3, U4.1, U4.40, U4.41, USB-OTG1.0, USB-OTG1.A1, USB-OTG1.A12, USB-OTG1.B1, USB-OTG1.B12, USB-UART1.0, USB-UART1.A1, USB-UART1.A12, USB-UART1.B1, USB-UART1.B12, pUEXT1.0, pUEXT1.2
unnamed: BUT1.1, R15.2
unnamed: C3.1, D2.1, FET1.2, U2.1, U2.4
unnamed: CHARGING1.1, R2.1
unnamed: D1.2, USB-UART1.A4, USB-UART1.A9, USB-UART1.B4, USB-UART1.B9
unnamed: D3.2, USB-OTG1.A4, USB-OTG1.A9, USB-OTG1.B4, USB-OTG1.B9
unnamed: L1.1, U2.3
unnamed: LED1.2, R13.2
unnamed: R2.2, U1.1
unnamed: R3.2, USB-UART1.B5
unnamed: R4.1, U1.5
unnamed: R5.2, USB-UART1.A5
unnamed: R10.1, R11.1, U2.5
unnamed: R12.1, U3.5
unnamed: R12.2, R22.1, T2.2, U3.6
unnamed: R16.2, USB-OTG1.A5
unnamed: R17.2, USB-OTG1.B5
unnamed: R22.2, T1.1
unnamed: R23.1, T1.2, U3.4
unnamed: R23.2, T2.1
unnamed: R24.1, U3.8
VBAT: BAT1.1, FET1.3, R6.1, U1.3

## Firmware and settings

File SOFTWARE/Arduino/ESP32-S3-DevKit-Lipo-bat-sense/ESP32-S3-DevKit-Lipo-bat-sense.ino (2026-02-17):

/*
   ============================================================
   ESP32-S3-DevKit-Lipo
   Battery Voltage + External Power Presence Monitor
   ============================================================

   GPIO6  -> Battery measurement
   GPIO5  -> External power sense
   GPIO38 -> Onboard LED (ACTIVE LOW)

   LED ON  = External power present
   LED OFF = Running on battery
*/

//////////////////////////////////////////////////////////////
// ---------------- PIN DEFINITIONS ------------------------
//////////////////////////////////////////////////////////////

#define LED_PIN        38
#define BAT_ADC_PIN    6    // GPIO6 (Battery)
#define PWR_ADC_PIN    5    // GPIO5 (External power)

//////////////////////////////////////////////////////////////
// ------------- ADC CONFIGURATION -------------------------
//////////////////////////////////////////////////////////////

#define ADC_RESOLUTION 4095.0
#define ADC_REF        3.3

// Correct ratios from schematic
#define BAT_DIVIDER_RATIO  4.1333
#define PWR_DIVIDER_RATIO  5.6808

// 5V through divider gives ~880mV at ADC
// Anything above 400mV means external power present
#define PWR_PRESENT_THRESHOLD 400

//////////////////////////////////////////////////////////////
// ------------------- LED FUNCTIONS -----------------------
//////////////////////////////////////////////////////////////

void ledInit()
{
  pinMode(LED_PIN, OUTPUT);
  digitalWrite(LED_PIN, HIGH); // LED OFF (active LOW)
}

void ledOn()
{
  digitalWrite(LED_PIN, LOW);
}

void ledOff()
{
  digitalWrite(LED_PIN, HIGH);
}

//////////////////////////////////////////////////////////////
// ------------------- VOLTAGE READ ------------------------
//////////////////////////////////////////////////////////////

float readVoltage(uint8_t pin, float dividerRatio)
{
  uint32_t adcRaw = analogRead(pin);

  float adcVoltage = (adcRaw / ADC_RESOLUTION) * ADC_REF;
  float realVoltage = adcVoltage * dividerRatio;

  return realVoltage;
}

uint16_t readRawMilliVolts(uint8_t pin)
{
  uint32_t adcRaw = analogRead(pin);
  float adcVoltage = (adcRaw / ADC_RESOLUTION) * ADC_REF;
  return (uint16_t)(adcVoltage * 1000.0);
}

//////////////////////////////////////////////////////////////
// ---------------------- SETUP ----------------------------
//////////////////////////////////////////////////////////////

void setup()
{
  Serial.begin(115200);
  delay(1000);

  Serial.println();
  Serial.println("Power Monitor Started");
  Serial.println("--------------------------------");

  analogReadResolution(12);

  ledInit();
}

//////////////////////////////////////////////////////////////
// ----------------------- LOOP ----------------------------
//////////////////////////////////////////////////////////////

void loop()
{
  float batteryVoltage = readVoltage(BAT_ADC_PIN, BAT_DIVIDER_RATIO);
  uint16_t pwrRawMv = readRawMilliVolts(PWR_ADC_PIN);

  bool externalPowerPresent = (pwrRawMv > PWR_PRESENT_THRESHOLD);

  Serial.print("Battery Voltage: ");
  Serial.print(batteryVoltage, 3);
  Serial.println(" V");

  if (externalPowerPresent)
  {
    Serial.println("External Power: PRESENT");
    ledOn();
  }
  else
  {
    Serial.println("External Power: NOT PRESENT");
    ledOff();
  }

  Serial.println("--------------------------------");
  delay(2000);
}

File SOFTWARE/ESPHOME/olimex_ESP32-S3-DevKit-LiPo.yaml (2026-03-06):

esphome:
  name: esp32-s3-node
  comment: Olimex ESP32-S3-DevKit-Lipo power-aware template

esp32:
  board: esp32-s3-devkitc-1
  framework:
    type: arduino

psram:
  mode: octal
  speed: 80MHz

# ================= SYSTEM =================

logger:
  baud_rate: 115200

api:

ota:

# ================= WIFI =================

wifi:
  ssid: !secret wifi_ssid
  password: !secret wifi_password

  ap:
    ssid: "ESP32-S3 Fallback"
    password: "fallback123"

  power_save_mode: light

captive_portal:

# ================= USER INPUT =================

binary_sensor:

  # User button
  - platform: gpio
    name: "User Button"
    pin:
      number: GPIO0
      mode: INPUT_PULLUP
      inverted: true

# ================= LED =================

output:
  - platform: gpio
    id: led_out
    pin:
      number: GPIO38
      inverted: true

light:
  - platform: binary
    id: status_led
    name: "Status LED"
    output: led_out

# ================= POWER MONITORING =================

sensor:

  # Battery voltage
  - platform: adc
    id: vbat
    pin: GPIO6
    attenuation: 11db
    update_interval: 30s
    filters:
      - multiply: 4.133
    name: "Battery Voltage"
    unit_of_measurement: "V"
    accuracy_decimals: 2

  # External power voltage
  - platform: adc
    id: vext
    pin: GPIO5
    attenuation: 11db
    update_interval: 30s
    filters:
      - multiply: 1.468
    name: "External Power Voltage"
    unit_of_measurement: "V"
    accuracy_decimals: 2

  # Battery percentage
  - platform: template
    name: "Battery Level"
    unit_of_measurement: "%"
    accuracy_decimals: 0
    update_interval: 30s
    lambda: |-
      float v = id(vbat).state;
      float p = (v - 3.2) / (4.2 - 3.2) * 100.0;
      if (p < 0) p = 0;
      if (p > 100) p = 100;
      return p;

# ================= POWER STATUS =================

binary_sensor:
  - platform: template
    id: ext_power
    name: "External Power Present"
    lambda: |-
      return id(vext).state > 4.0;
    update_interval: 10s

# ================= pUEXT BUS =================

uart:
  - id: puext_uart
    tx_pin: GPIO17
    rx_pin: GPIO18
    baud_rate: 115200

i2c:
  - id: puext_i2c
    scl: GPIO47
    sda: GPIO48
    scan: true
    frequency: 400kHz

spi:
  - id: puext_spi
    clk_pin: GPIO12
    mosi_pin: GPIO11
    miso_pin: GPIO13

# ================= CONNECTION WATCHDOG =================

interval:
  - interval: 60s
    then:
      - if:
          condition:
            not:
              wifi.connected:
          then:
            - logger.log: "WiFi lost, restarting..."
            - button.press: restart_button

button:
  - platform: restart
    id: restart_button
    name: "Restart Device"

# ================= LED STATUS BEHAVIOR =================

interval:
  - interval: 5s
    then:
      - light.toggle: status_led

# ================= BATTERY PROTECTION =================

interval:
  - interval: 5min
    then:
      - if:
          condition:
            lambda: |-
              return id(vbat).state < 3.3;
          then:
            - logger.log: "Low battery entering deep sleep"
            - deep_sleep.enter: deep_sleep_control

deep_sleep:
  id: deep_sleep_control
  sleep_duration: 30min

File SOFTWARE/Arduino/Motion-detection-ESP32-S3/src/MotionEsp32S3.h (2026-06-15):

#pragma once

#include <Arduino.h>
#include <esp_attr.h>
#include <esp_err.h>
#include <esp_wifi.h>

class MotionEsp32S3 {
public:
  static constexpr uint8_t kBins = 32;
  static constexpr uint8_t kMaxLinks = 8;
  static constexpr uint16_t kMaxCsiBytes = 384;

  struct Config {
    uint16_t reportIntervalMs = 200;
    uint16_t calibrationMs = 8000;
    uint16_t staleLinkMs = 4000;
    uint8_t queueDepth = 24;
    uint8_t maxPacketsPerUpdate = 80;
    float threshold = 1.1f;
    float sensitivity = 1.0f;
    float fastAlpha = 0.35f;
    float baselineAlpha = 0.010f;
    float calibrationAlpha = 0.080f;
    float noiseAlpha = 0.050f;
    bool filterByMac = false;
    uint8_t targetMac[6] = {0, 0, 0, 0, 0, 0};
    uint8_t allowedMacCount = 0;
    uint8_t allowedMacs[kMaxLinks][6] = {{0}};
  };

  struct Reading {
    uint32_t uptimeMs = 0;
    uint32_t packets = 0;
    uint32_t dropped = 0;
    uint8_t links = 0;
    int8_t rssi = 0;
    float score = 0.0f;
    float peak = 0.0f;
    float threshold = 0.0f;
    uint8_t confidence = 0;
    bool motion = false;
    char bestMac[18] = "00:00:00:00:00:00";
  };

  struct LinkReading {
    bool active = false;
    uint8_t mac[6] = {0, 0, 0, 0, 0, 0};
    char macText[18] = "00:00:00:00:00:00";
    uint32_t packets = 0;
    uint32_t ageMs = 0;
    int8_t rssi = 0;
    uint8_t channel = 0;
    uint16_t csiLength = 0;
    float score = 0.0f;
    float peak = 0.0f;
    uint8_t confidence = 0;
    bool motion = false;
  };

  MotionEsp32S3();

  bool begin();
  bool begin(const Config &config);
  void end();

  bool update();
  void resetBaseline();

  const Reading &reading() const;
  bool linkReading(uint8_t index, LinkReading &out) const;
  uint8_t linkCount() const;

  bool motion() const;
  float score() const;
  float threshold() const;
  float sensitivity() const;
  uint32_t packets() const;
  uint32_t droppedPackets() const;

  void clearMacFilter();
  void setMacFilter(const uint8_t mac[6]);
  bool filterToBestLink();
  void setThreshold(float threshold);
  void setSensitivity(float sensitivity);

  String json() const;
  String fingerprintCsv(const char *label = "") const;
  String fingerprintCsvAll(const char *label = "") const;

  static String fingerprintCsvHeader();
  static String macToString(const uint8_t mac[6]);
  static const char *dashboardHtml();

private:
  struct FeaturePacket {
    uint8_t mac[6];
    int8_t rssi;
    uint8_t channel;
    bool firstWordInvalid;
    uint16_t csiLength;
    uint32_t rxTimestampUs;
    int8_t csi[kMaxCsiBytes];
  };

  struct LinkState {
    bool active = false;
    bool initialized = false;
    uint8_t mac[6] = {0, 0, 0, 0, 0, 0};
    uint32_t packets = 0;
    uint32_t firstSeenMs = 0;
    uint32_t lastSeenMs = 0;
    int8_t rssi = 0;
    uint8_t channel = 0;
    uint16_t csiLength = 0;
    float fast[kBins] = {0};
    float baseline[kBins] = {0};
    float noise[kBins] = {0};
    float last[kBins] = {0};
    float score = 0.0f;
    float smoothed = 0.0f;
    float peak = 0.0f;
    bool motion = false;
  };

  static void IRAM_ATTR onCsi(void *ctx, wifi_csi_info_t *data);
  void IRAM_ATTR enqueueCsi(wifi_csi_info_t *data);
  void processPacket(const FeaturePacket &packet);
  int findOrCreateLink(const uint8_t mac[6], uint32_t nowMs);
  void resetTracking(uint32_t nowMs);
  void rebuildReading(uint32_t nowMs);
  void fillLinkReading(const LinkState &link, LinkReading &out, uint32_t nowMs) const;
  void appendFingerprintRow(String &out, const LinkState *link, uint32_t nowMs, const char *label) const;
  static void copyMacText(const uint8_t mac[6], char *out, size_t outSize);

  Config _config;
  void *_queue = nullptr;
  bool _started = false;
  bool _newReport = false;
  uint32_t _startedMs = 0;
  uint32_t _lastReportMs = 0;
  volatile uint32_t _dropped = 0;
  LinkState _links[kMaxLinks];
  Reading _reading;
};

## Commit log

2023-07-28 initial upload
    [BM10B-SRSS-TB(JST_GH_BM10B-GHS-TBT_1x10-1MP_P1.25mm_Vertical).step, ESP32-S3-DevKit-LiPo_Rev_B-BOM.ods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]
2024-07-05 Update
    Diemsnions
    [ESP32-S3-DevKit-LiPo_Rev_B_DIMM.kicad_pcb]
2026-02-17 New demo
    Arduino demo for battery sense and battery measurement
2026-02-24 Update
    New demo and fixed Arduino settings to fit the PSRAM type
    [ESP32-S3-chip-info-demo.ino]

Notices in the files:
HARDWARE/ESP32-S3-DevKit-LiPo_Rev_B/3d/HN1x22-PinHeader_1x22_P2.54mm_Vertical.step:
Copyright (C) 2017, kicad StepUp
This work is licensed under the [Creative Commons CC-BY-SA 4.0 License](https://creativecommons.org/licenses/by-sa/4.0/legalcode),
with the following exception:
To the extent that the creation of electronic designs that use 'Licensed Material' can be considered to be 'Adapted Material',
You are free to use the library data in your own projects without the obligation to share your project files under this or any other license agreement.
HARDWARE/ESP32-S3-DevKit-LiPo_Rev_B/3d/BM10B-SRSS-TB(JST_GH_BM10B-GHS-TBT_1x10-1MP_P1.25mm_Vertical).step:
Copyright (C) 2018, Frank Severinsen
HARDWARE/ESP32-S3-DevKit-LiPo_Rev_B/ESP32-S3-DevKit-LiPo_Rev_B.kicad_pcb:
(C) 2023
